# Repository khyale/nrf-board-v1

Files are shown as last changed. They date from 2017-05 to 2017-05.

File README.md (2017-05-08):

# nrf-board-v1
Projeto PCB de módulo transceptor digital de 2.4GHz Nordic NRF24L01P

Projeto de placa de circuito impresso de tranceptor digital operando 
na faixa de 2,4GHz, baseado no chip da Nordic Semiconductor, NRF24L01P.
A placa possui conector de barras de pinos (2x4) para conexão com uC 
através dos sinais CSN, MOSI, MISO, SCK (interface SPI), /IRQ (interrupção)
, alem do VDD e GND.

Utilizou-se um conector SMA horizontal para conexão com a antena 
dipolo de 2,4GHz.

O circuito não foi projetado com regulador de tensão, com o objetivo de reduzir
custo e manter o baixo consumo de energia, sendo ideal para aplicações utilizem baterias.

A  princípio, o módulo pode ser alimentado com tensões de 1.9 a 3.6V (2 a 3 pilhas de NiMH)
A corrente de standby é de apenas 26uA.

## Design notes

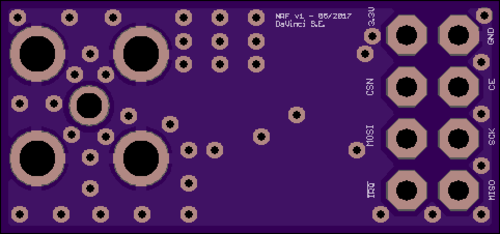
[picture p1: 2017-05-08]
brd/oshpark/nrf-v1-boardbottom.png

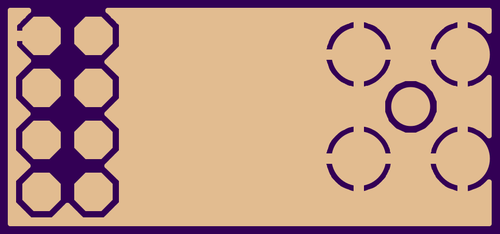
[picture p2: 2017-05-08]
brd/oshpark/nrf-v1-bottomlayer.png

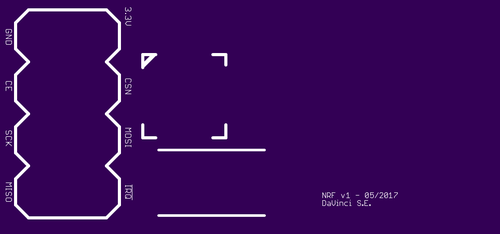
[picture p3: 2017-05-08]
brd/oshpark/nrf-v1-topsilkscreen.png

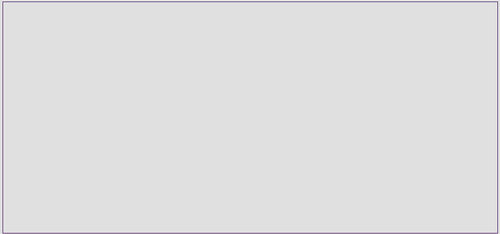
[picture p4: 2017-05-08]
brd/oshpark/nrf-v1-boardoutline.png

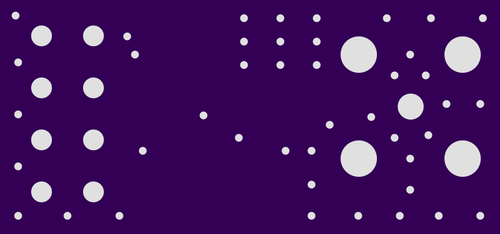
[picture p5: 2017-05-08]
brd/oshpark/nrf-v1-drills.png

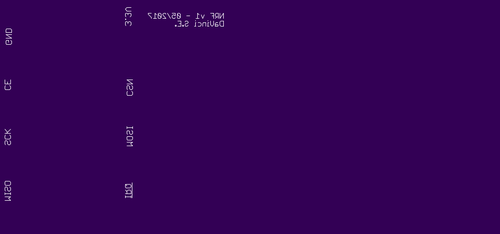
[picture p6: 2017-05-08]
brd/oshpark/nrf-v1-bottomsilkscreen.png

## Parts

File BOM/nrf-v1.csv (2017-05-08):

Part | Value | Device | Package | Description
C1 | 22pF | UQCL2A220JAT2A/500 | CAPC1005X60N | Capacitor 0402
C2 | 22pF | UQCL2A220JAT2A/500 | CAPC1005X60N | Capacitor 0402
C3 | 2.2nF | UQCL2A220JAT2A/500 | CAPC1005X60N | Capacitor 0402
C4 | 4.7pF | UQCL2A220JAT2A/500 | CAPC1005X60N | Capacitor 0402
C5 | 1.5pF | UQCL2A220JAT2A/500 | CAPC1005X60N | Capacitor 0402
C6 | 1pF | C-EU01005 | C01005 | CAPACITOR, European symbol
C7 | 33nF | UQCL2A220JAT2A/500 | CAPC1005X60N | Capacitor 0402
C8 | 1nF | UQCL2A220JAT2A/500 | CAPC1005X60N | Capacitor 0402
C9 | 10nF | UQCL2A220JAT2A/500 | CAPC1005X60N | Capacitor 0402
CONN1-PIN | M04X2 | M04X2 | 2X4 | .1 header, two rows of four."
CONN2-SMA | BU-SMA-H | BU-SMA-H | BU-SMA-H | FEMALE SMA CONNECTOR
L1 | 8.2nH | INDUCTOR0402 | C0402 | Inductors
L2 | 2.7nH | INDUCTOR0402 | C0402 | Inductors
L3 | 3.9nH | INDUCTOR0402 | C0402 | Inductors
R1 | 22K | TNPW040220K0BEED | RESC1005X40N | RESISTOR, 0402
U1 | NRF24L01SMD | NRF24L01SMD | QFN20 | 2.4GHz Low Power Transceiver
X1 | 16MHz | CRYSTALTXC-7A | CRYSTAL-TXC-7A | Various standard crystals. Proven footprints. Spark Fun Electronics SKU : COM-00534

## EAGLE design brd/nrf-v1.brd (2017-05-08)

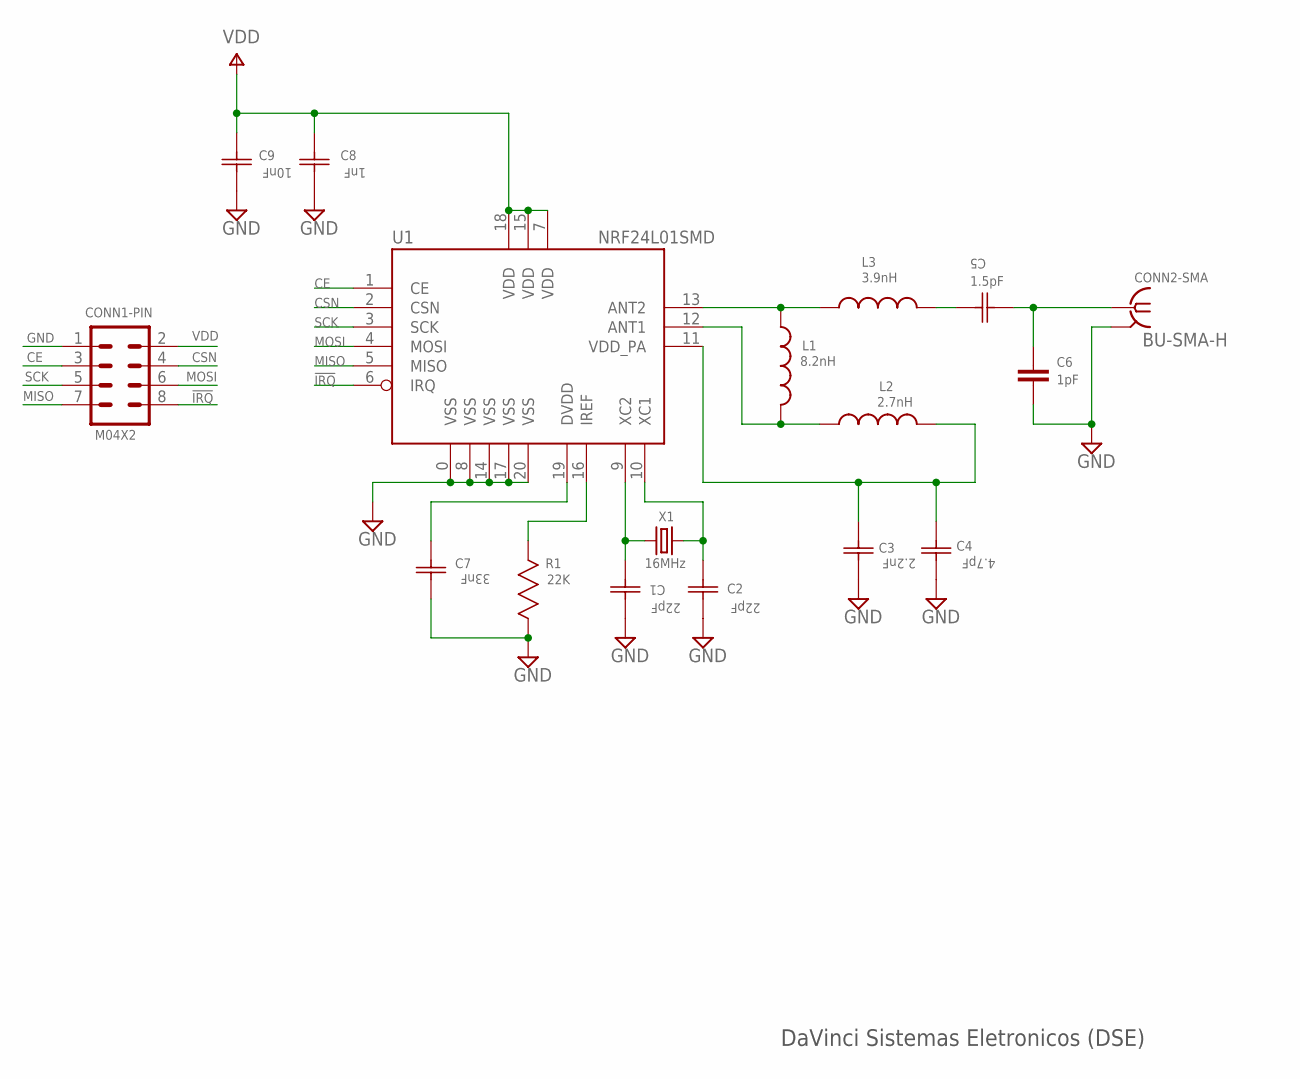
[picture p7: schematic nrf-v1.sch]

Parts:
C1, C2: 22pF; CAPC1005X60N
C3: 2.2nF; CAPC1005X60N
C4: 4.7pF; CAPC1005X60N
C5: 1.5pF; CAPC1005X60N
C6: 1pF; C01005
C7: 33nF; CAPC1005X60N
C8: 1nF; CAPC1005X60N
C9: 10nF; CAPC1005X60N
CONN1-PIN: M04X2; 2X4
CONN2-SMA: BU-SMA-H
L1: 8.2nH; C0402
L2: 2.7nH; C0402
L3: 3.9nH; C0402
R1: 22K; RESC1005X40N
U1: NRF24L01SMD; QFN20
X1: 16MHz; CRYSTAL-TXC-7A

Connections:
!IRQ: CONN1-PIN.8, U1.6 (IRQ)
CE: CONN1-PIN.3, U1.1 (CE)
CSN: CONN1-PIN.4, U1.2 (CSN)
GND: C1.2 (C1), C2.2 (C1), C3.2 (C1), C4.2 (C1), C6.2, C7.2 (C1), C8.2 (C1), C9.2 (C1), CONN1-PIN.1, CONN2-SMA.2, CONN2-SMA.3 (2), CONN2-SMA.4 (2), CONN2-SMA.5 (2), R1.1, U1.0 (VSS), U1.8 (VSS), U1.14 (VSS), U1.17 (VSS), U1.20 (VSS)
MISO: CONN1-PIN.7, U1.5 (MISO)
MOSI: CONN1-PIN.6, U1.4 (MOSI)
unnamed: C1.1 (C2), U1.9 (XC2), X1.P$1 (1)
unnamed: C2.1 (C2), U1.10 (XC1), X1.P$2 (2)
unnamed: L1.1, L3.1, U1.13 (ANT2)
unnamed: C5.1 (C2), L3.2
unnamed: C5.2 (C1), C6.1, CONN2-SMA.1
unnamed: L1.2, L2.1, U1.12 (ANT1)
unnamed: C3.1 (C2), C4.1 (C2), L2.2, U1.11 (VDD_PA)
unnamed: C7.1 (C2), U1.19 (DVDD)
unnamed: R1.2, U1.16 (IREF)
SCK: CONN1-PIN.5, U1.3 (SCK)
VDD: C8.1 (C2), C9.1 (C2), CONN1-PIN.2, U1.7 (VDD), U1.15 (VDD), U1.18 (VDD)

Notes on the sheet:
DaVinci Sistemas Eletronicos (DSE)

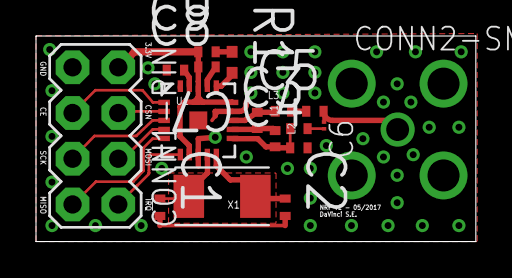
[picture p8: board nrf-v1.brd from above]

Board: 2 copper layers, 24.4 x 11.4 mm, 17 parts (0 on the bottom side), 17 nets.

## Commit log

2017-05-08 adicionado a BOM
    [nrf-v1.csv]
2017-05-08 deletado a bom
    [nrf-v1.csv]
2017-05-08 arquivos adicionados
    [nrf-v1.brd, nrf-v1.csv, nrf-v1.sch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]

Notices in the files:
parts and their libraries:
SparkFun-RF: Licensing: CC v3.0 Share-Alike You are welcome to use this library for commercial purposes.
